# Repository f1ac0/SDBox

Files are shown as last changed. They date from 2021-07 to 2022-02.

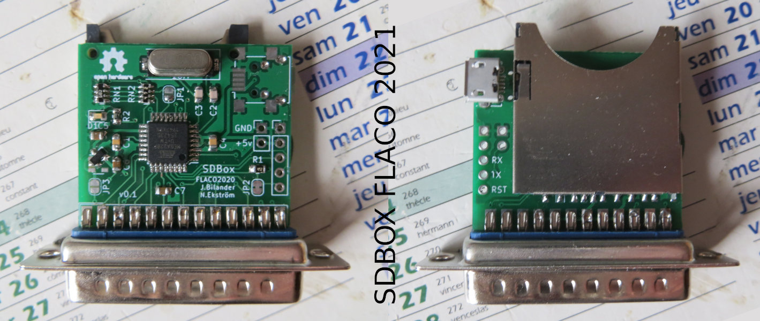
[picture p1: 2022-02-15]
SDBOX FLACO 2021.jpg

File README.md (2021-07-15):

# SDBox
The SDBox project by jbilander and based on the SPI adapter by niklasekstrom is a wonderful parallel sdcard reader for Amiga computers. Thank you guys for sharing it under GPLv3 license.
https://github.com/jbilander/sdbox

I use it to transfer files either to my A500 with internal IDE adapter or to my A600 or 1200 without blocking the PCMCIA port.

The project in this repository is just a recreated board making use of the bare chips instead of breadboard modules.
- It is smaller
- It accommodates big SD cards instead of microSD
- It takes its power from a Mini or Micro USB or from a pin header (I also use this header as an output to power a serial adapter using the same power pack)
- It does not include the 2nd LED and power switch
- It uses SMD stuff (maybe harder to solder)
- It is also designed using the KiCAD EDA

I guess it is not better than the original, just different for those who prefer tiny stuff.

For the software part, it works with the original firmware and driver.

# Disclaimer
This is a hobbyist project, it comes with no warranty and no support. Also remember that the Amiga machines are about 30 years old and may fail because of such hardware expansions.

This version is not endorsed by the original authors, please don't bother them with issues you might have because of it.

I publish this work using the same license as the original : GPLv3.

If you find it useful, please reward the original authors.

# BOM
- 1x Male DB25 header
- 1x SDCARD socket (SDP11-4-12B on the schematic I have but known with other names online)
- 1x ATMEGA 328p-au
- 1x SPX3819M5-L-3-3 3.3v LDO
- 1x 16MHz HC-49S crystal
- 2x 1uF (or more) 0805 capacitors
- 3x 100nF 0805 capacitors
- 2x 22pf 0805 capacitors
- 1x 4.7K 0805 resistor
- 1x 6.8K 0603x4 resistor array
- 1x 4.7K 0603x4 resistor array
- 1x optional 0805 LED and 0805 resistor (330 ohm or more)
For power, install the one you need :
- 1x Mini USB Female Socket 4 foot
- 1x Micro USB Female Socket B type 4.85 horn connector
- 1x 1x2 2.54mm pin header

# Making it
I recommend 1.6mm PCB since it is sandwiched between the pins of the DB25 connector.

Check for shorts at least between 5V, 3.3V, and GND traces before applying power !

The programming port does not need to be soldered since it needs to be programmed just once : you can just hold it in place during the few seconds required for programming.

The blank 328p chip needs to be programmed using its SPI port : for example connect an arduino as ISP, https://www.instructables.com/Burn-a-New-Bootloader-Arduino-Pro-Mini/
```
Arduino ------------------- this board
5V (VCC) ------------------ +5V
GND ----------------------- GND
Pin 10 -------------------- RST
Pin 11 -------------------- MOSI
Pin 12 -------------------- MISO
Pin 13 -------------------- SCK
```

Then to program the SDBox firmware on the 328p :
```
~/arduino/hardware/tools/avr/bin/avrdude -C ~/arduino/hardware/tools/avr/etc/avrdude.conf -v -patmega328p -cavrisp -P/dev/ttyUSB0 -b19200 -D -Uflash:w:main.hex:i
```

Alternatively, you may first program an arduino bootloader using the arduino IDE. Then you will be able to later program and update the SDBox firmware through UART TX and RX pins using a USB to serial adapter with :
```
~/arduino/hardware/tools/avr/bin/avrdude -C ~/arduino/hardware/tools/avr/etc/avrdude.conf -v -patmega328p -carduino -P/dev/ttyUSB0 -b57600 -D -Uflash:w:main.hex:i
```

# Using it
- Plug it to the parallel port
- Plug it to power block
- Insert SDcard
- Apply power
- Turn Amiga on
- Install the drivers
- Mount the sdcard using
```
mount devs:SD0
```
- Unmount the sdcard using
```
assign SD0: DISMOUNT
```
replace DISMOUNT with REMOVE on Kickstart 1.3.

If you care about your Amiga, this is a bad idea to plug or unplug the parallel port while live.

If you care about the data on the card or the card itself, it might also be a bad idea to plug or unplug it while power is applied. I personally have done so several times already without problem so far, just dismount the partition before unplugging.

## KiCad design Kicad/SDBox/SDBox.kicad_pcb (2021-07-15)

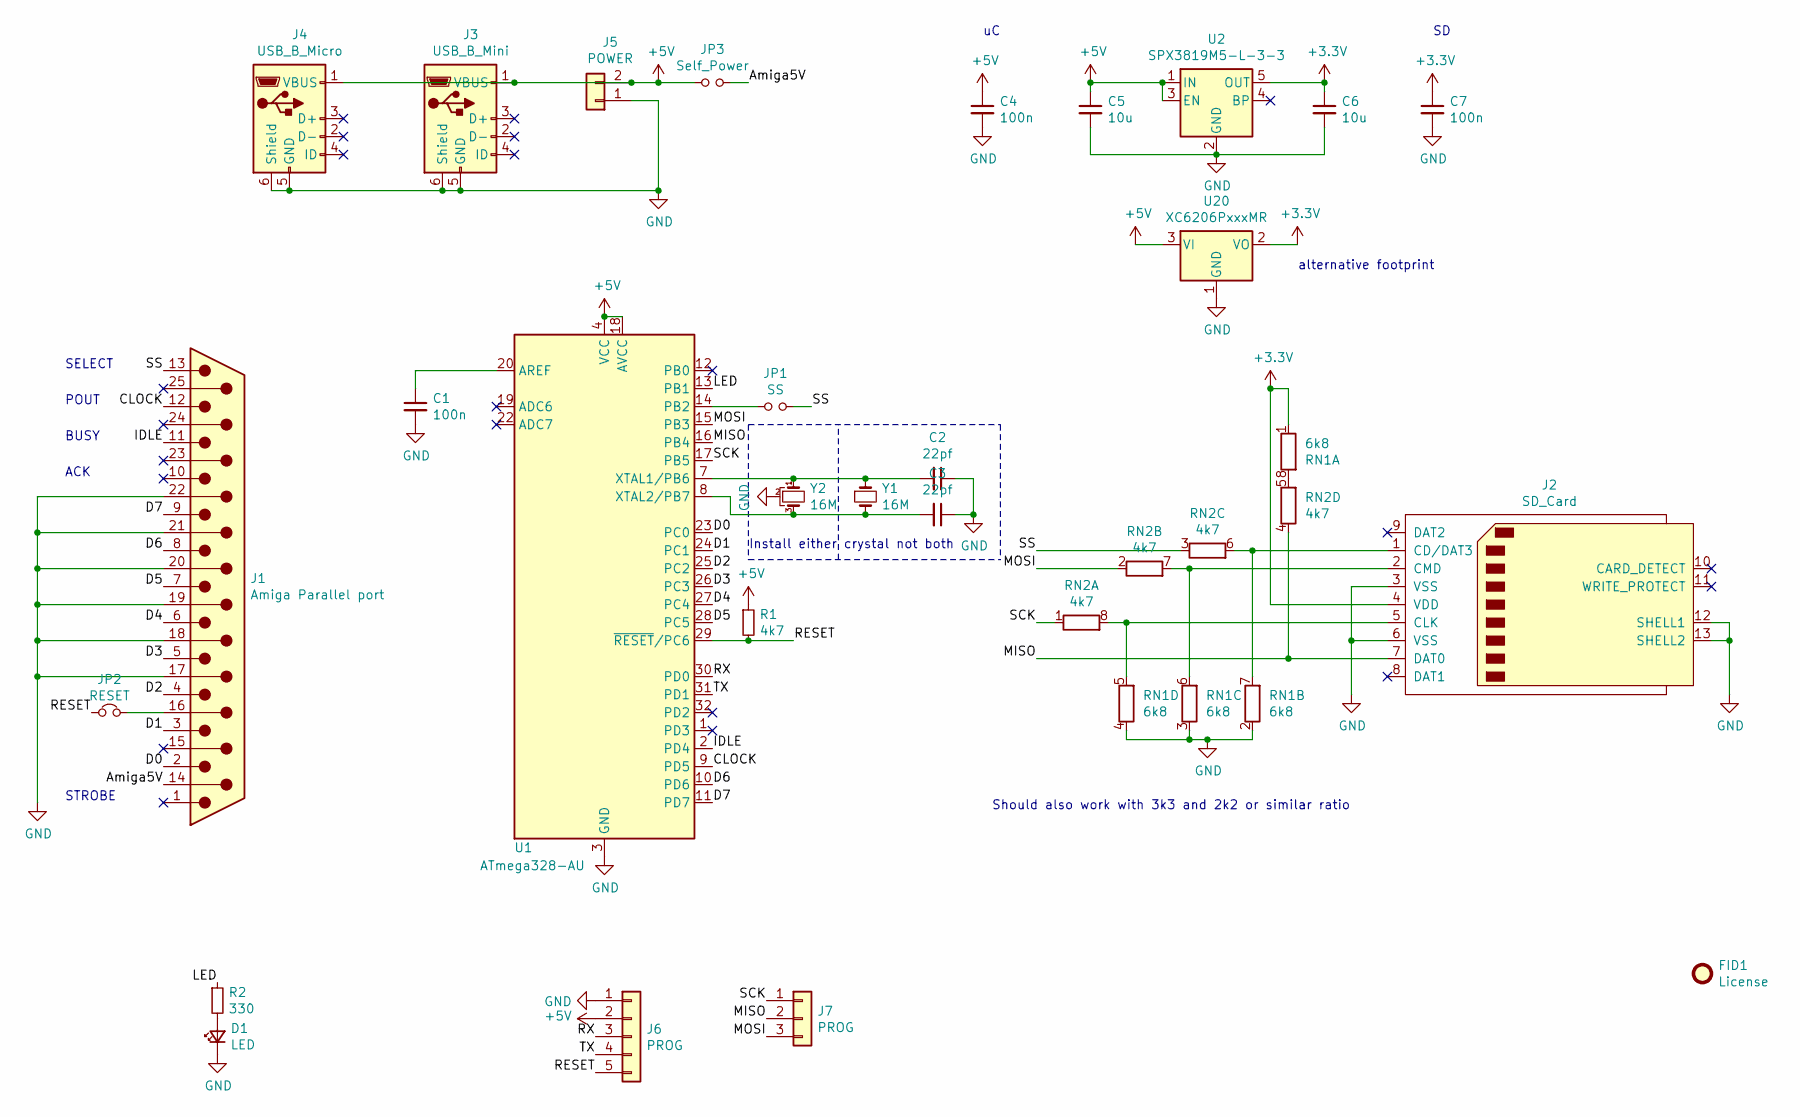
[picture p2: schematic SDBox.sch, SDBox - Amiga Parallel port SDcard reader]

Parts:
C1, C4, C7: 100n; C_0805_2012Metric
C2, C3: 22pf; C_0805_2012Metric
C5, C6: 10u; C_0805_2012Metric
D1: LED; LED_0805_2012Metric
FID1: License; OSHW-Logo2_7.3x6mm_SilkScreen
J1: Amiga Parallel port; DSUB-25_Male_EdgeMount_P2.77mm
J2: SD_Card; Conn_SDcard
J3: USB_B_Mini; USB_Mini-B_Lumberg_2486_01_Horizontal
J4: USB_B_Micro; USB_Micro-B_Molex-105017-0001
J5: POWER; PinHeader_1x02_P2.54mm_Vertical
J6: PROG; PinHeader_1x05_P2.54mm_Vertical
J7: PROG; PinHeader_1x03_P2.54mm_Vertical
JP1: SS; SolderJumper-2_P1.3mm_Open_RoundedPad1.0x1.5mm
JP2: RESET; SolderJumper-2_P1.3mm_Bridged_RoundedPad1.0x1.5mm
JP3: Self_Power; SolderJumper-2_P1.3mm_Open_RoundedPad1.0x1.5mm
R1: 4k7; R_0805_2012Metric
R2: 330; R_0805_2012Metric
RN1: 6k8; R_Array_Convex_4x0603
RN2: 4k7; R_Array_Convex_4x0603
U1: ATmega328-AU; TQFP-32_7x7mm_P0.8mm
U2: SPX3819M5-L-3-3; SOT-23-5
U20: XC6206PxxxMR; SOT-23
Y1: 16M; Crystal_SMD_HC49-SD
Y2: 16M; MURATA_CSTCE

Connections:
+3V3: C6.1, C7.1, J2.4 (VDD), RN1.1 (R1.1), U2.5 (OUT), U20.2 (VO)
+5V: C4.1, C5.1, J3.1 (VBUS), J4.1 (VBUS), J5.2, J6.2, JP3.1, R1.1, U1.4 (VCC), U1.6 (VCC), U1.18 (AVCC), U2.1 (IN), U2.3 (EN), U20.3 (VI)
/Amiga5V: J1.14, JP3.2
/CLOCK: J1.12, U1.9 (PD5)
/D0: J1.2, U1.23 (PC0)
/D1: J1.3, U1.24 (PC1)
/D2: J1.4, U1.25 (PC2)
/D3: J1.5, U1.26 (PC3)
/D4: J1.6, U1.27 (PC4)
/D5: J1.7, U1.28 (PC5)
/D6: J1.8, U1.10 (PD6)
/D7: J1.9, U1.11 (PD7)
/IDLE: J1.11, U1.2 (PD4)
/LED: R2.1, U1.13 (PB1)
/MISO: J2.7 (DAT0), J7.2, RN2.4 (R4.1), U1.16 (PB4)
/MOSI: J7.3, RN2.2 (R2.1), U1.15 (PB3)
/RESET: J6.5, JP2.1, R1.2, U1.29 (~RESET~/PC6)
/RX: J6.3, U1.30 (PD0)
/SCK: J7.1, RN2.1 (R1.1), U1.17 (PB5)
/SS: J1.13, JP1.2, RN2.3 (R3.1)
/TX: J6.4, U1.31 (PD1)
GND: C1.2, C2.1, C3.1, C4.2, C5.2, C6.2, C7.2, D1.1 (K), J1.17, J1.18, J1.19, J1.20, J1.21, J1.22, J2.3 (VSS), J2.6 (VSS), J2.12 (SHELL1), J2.13 (SHELL2), J3.5 (GND), J3.6 (Shield), J4.5 (GND), J4.6 (Shield), J5.1, J6.1, RN1.2 (R2.1), RN1.3 (R3.1), RN1.4 (R4.1), U1.3 (GND), U1.5 (GND), U1.21 (GND), U2.2 (GND), U20.1 (GND), Y2.2
unnamed: C1.1, U1.20 (AREF)
unnamed: C2.2, U1.7 (XTAL1/PB6), Y1.1, Y2.1
unnamed: C3.2, U1.8 (XTAL2/PB7), Y1.2, Y2.3
unnamed: D1.2 (A), R2.2
unnamed: J1.16, JP2.2
unnamed: J2.1 (CD/DAT3), RN1.7 (R2.2), RN2.6 (R3.2)
unnamed: J2.2 (CMD), RN1.6 (R3.2), RN2.7 (R2.2)
unnamed: J2.5 (CLK), RN1.5 (R4.2), RN2.8 (R1.2)
unnamed: JP1.1, U1.14 (PB2)
unnamed: RN1.8 (R1.2), RN2.5 (R4.2)

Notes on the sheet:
POUT
BUSY
Should also work with 3k3 and 2k2 or similar ratio
SELECT
ACK
STROBE
Install either crystal not both
alternative footprint

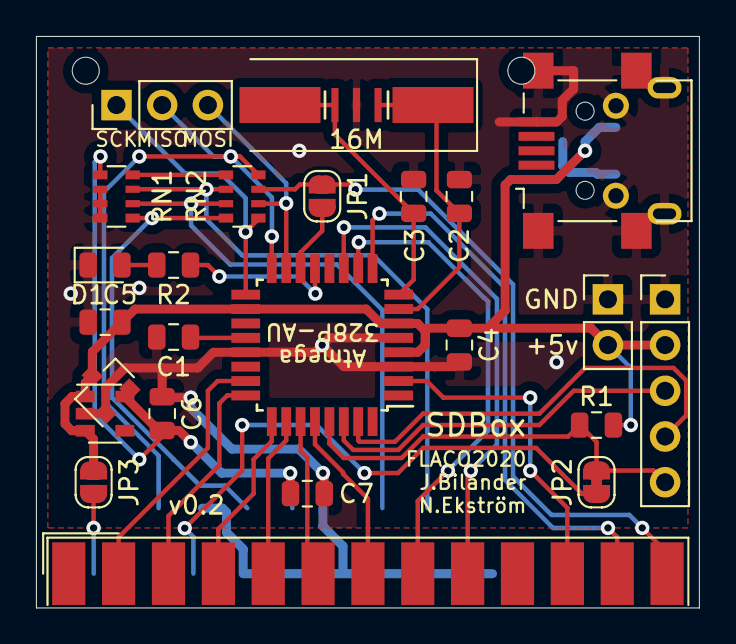
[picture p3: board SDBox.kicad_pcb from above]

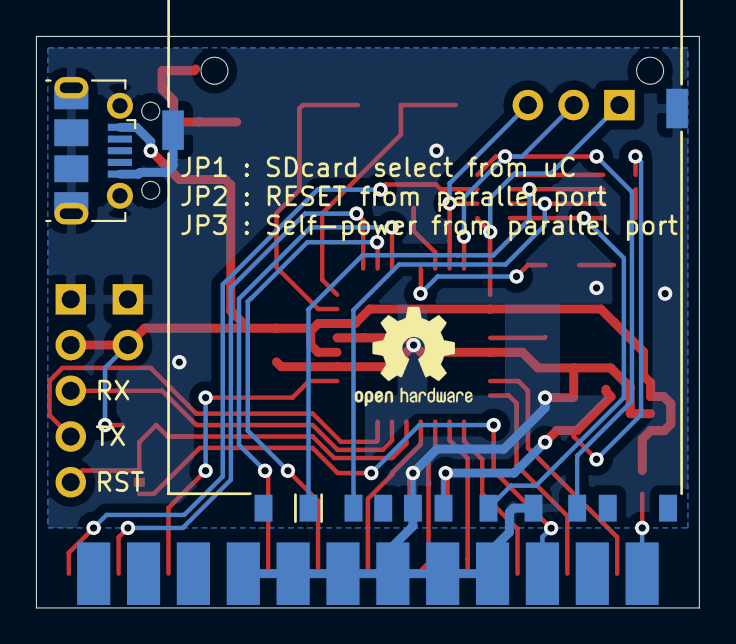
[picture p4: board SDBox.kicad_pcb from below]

Board: 2 copper layers, 36.8 x 31.8 mm, 28 parts (3 on the bottom side), 32 nets.

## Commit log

2020-07-30 Respository init with v0.1 KiCAD files, Readme and License
    [SDBox.kicad_pcb, SDBox.sch]
2020-09-23 Added CSTCE crystal footprint
    [SDBox.kicad_pcb, SDBox.sch]
2021-07-15 Kicad : 0.2 with broken SPI programming port
    [SDBox.kicad_pcb, SDBox.sch]

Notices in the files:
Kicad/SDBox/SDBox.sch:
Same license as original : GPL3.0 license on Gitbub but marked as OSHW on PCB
